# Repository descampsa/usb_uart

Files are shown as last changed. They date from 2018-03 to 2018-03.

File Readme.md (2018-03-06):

Isolated uart-usb converter.

Features:
- Silab CP2102N converter
- MAX12931 isolators
- Up to 3Mbaud UART, with hardware flow control (RTS/CTS)
- Supports 5V, 3.3V and 1.8V VCC
- Maximum withstand isolation voltage (VISO) : 3KV RMS
- Maximum working isolation voltage (VIOWM) : 445V RMS
- ABS plastic enclosure, with micro usb connector, and 0.1'' 6 pins header for uart

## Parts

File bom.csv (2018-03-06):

UBS_UART
N° Mouser | N° de fab. | Fabricant | N° client | Description | RoHS | Cycle de vie | Qté. | Prix (EUR) | Ext. : (EUR)
798-ZX62D-B-5PA830 | ZX62D-B-5PA8(30) | Hirose Electric |  | 5P RECEPTACLE | RoHS : conforme | Nouveau produit | 1 | 0,574 € | 0,57 €
538-22-28-8061 | 22-28-8061 | Molex |  | 2.54MM BREAKAWAY RA 6 CKT Tin | RoHS : conforme |  | 1 | 0,353 € | 0,35 €
710-885012206071 | 885012206071 | Wurth Electronics |  | WCAP-CSGP 100000pF 0603 10% 25V MLCC | RoHS : conforme |  | 6 | 0,04 € | 0,24 €
603-RC0603FR-071KL | RC0603FR-071KL | Yageo |  | 1K OHM 1% | RoHS : conforme |  | 4 | 0,082 € | 0,33 €
603-RC0603JR-074K7L | RC0603JR-074K7L | Yageo |  | 4.7K OHM 5% | RoHS : conforme |  | 2 | 0,082 € | 0,16 €
634-CP2102NA01GQFN20 | CP2102N-A01-GQFN20 | Silicon Laboratories |  | USB to UART bridge QFN20 | RoHS : conforme | Nouveau produit | 1 | 1,36 € | 1,36 €
700-MAX12931BASA+ | MAX12931BASA+ | Maxim Integrated |  | 2-Channel, 3.75kVRMS Digital Isolators | RoHS : conforme | Nouveau produit | 2 | 1,36 € | 2,72 €
789-P3A-20100562U | P3A-20100562U | New Age Enclosures |  | USB w/Open .062" PCB ABS Black 2x1x.5" | RoHS : conforme |  | 1 | 2,79 € | 2,79 €
749-VLP-250-R | VLP-250-R | BIVAR |  | Light Pipe Vert SMD Round Face | RoHS : conforme |  | 3 | 0,426 € | 1,28 €
530-0ZCJ0010FF2E | 0ZCJ0010FF2E | Bel |  | Fuse | RoHS : conforme |  | 1 | 0,09 € | 0,09 €
604-AP1608SRCPRV | AP1608SRCPRV | Kingbright |  | RED WATER CLEAR | RoHS : conforme |  | 3 | 0,107 € | 0,32 €
78-GMF05LC-HSF-GS08 | GMF05LC-HSF-GS08 | Vishay |  | ESD PRO LLP75-E4 | RoHS : conforme |  | 2 | 0,549 € | 1,10 €

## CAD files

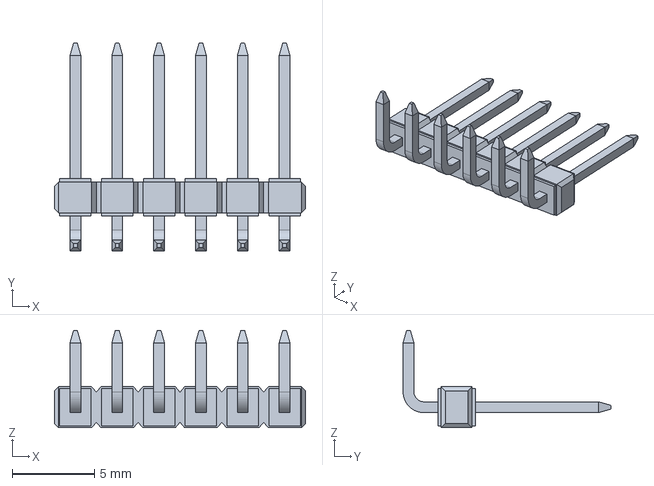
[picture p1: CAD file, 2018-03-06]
molex/022288061.step
15.2 x 12.6 x 5.92 mm

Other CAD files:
molex/022288061.stp

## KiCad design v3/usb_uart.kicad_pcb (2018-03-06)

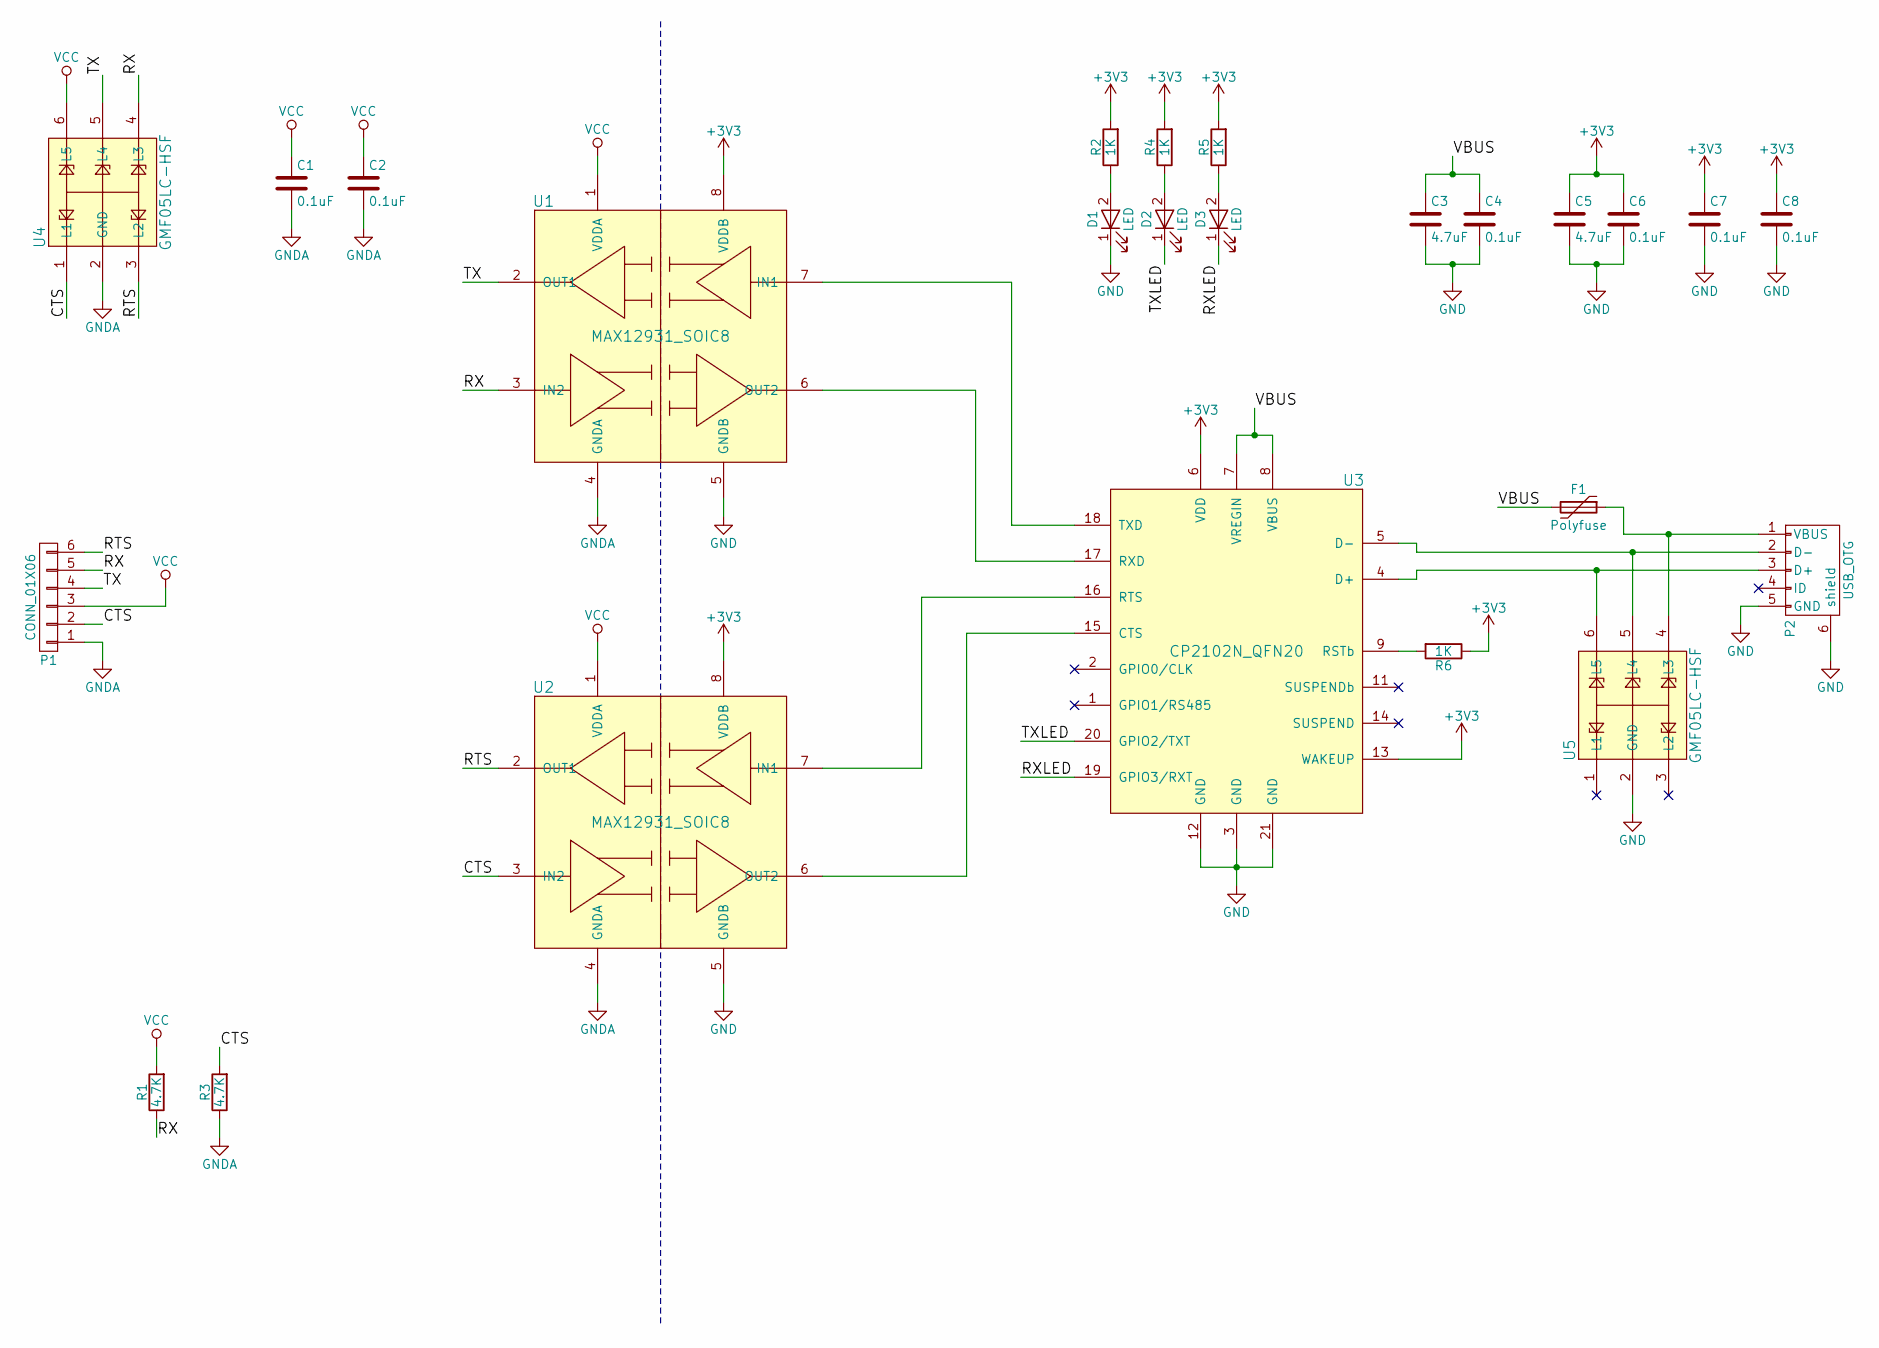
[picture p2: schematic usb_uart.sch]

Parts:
C1, C2, C4, C6, C7, C8: 0.1uF; C_0603
C3, C5: 4.7uF; C_0603
D1, D2, D3: LED; LED_0603
F1: Polyfuse; fuse_1206
P1: CONN_01X06; Pin_Header_Angled_1x06_Pitch2.54mm
P2: USB_OTG; ZX62D-B-5PA8
R1, R3: 4.7K; R_0603
R2, R4, R5, R6: 1K; R_0603
U1, U2: MAX12931_SOIC8; SOIC-8_3.9x4.9mm_Pitch1.27mm
U3: CP2102N_QFN20; QFN-20-1EP_3x3mm_Pitch0.5mm
U4, U5: GMF05LC-HSF; LLP75-6L

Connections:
+3V3: C5.1, C6.1, C7.1, C8.1, R2.2, R4.2, R5.2, R6.1, U1.8 (VDDB), U2.8 (VDDB), U3.6 (VDD), U3.13 (WAKEUP)
/CTS: P1.2, R3.2, U2.3 (IN2), U4.1 (L1)
/RTS: P1.6, U2.2 (OUT1), U4.3 (L2)
/RX: P1.5, R1.1, U1.3 (IN2), U4.4 (L3)
/RXLED: D3.1 (K), U3.19 (GPIO3/RXT)
/TX: P1.4, U1.2 (OUT1), U4.5 (L4)
/TXLED: D2.1 (K), U3.20 (GPIO2/TXT)
/VBUS: C3.1, C4.1, F1.2, U3.7 (VREGIN), U3.8 (VBUS)
GND: C3.2, C4.2, C5.2, C6.2, C7.2, C8.2, D1.1 (K), P2.5 (GND), P2.6 (shield), U1.5 (GNDB), U2.5 (GNDB), U3.3 (GND), U3.12 (GND), U3.21 (GND), U5.2 (GND)
GNDA: C1.2, C2.2, P1.1, R3.1, U1.4 (GNDA), U2.4 (GNDA), U4.2 (GND)
unnamed: D1.2 (A), R2.1
unnamed: D2.2 (A), R4.1
unnamed: D3.2 (A), R5.1
unnamed: F1.1, P2.1 (VBUS), U5.4 (L3)
unnamed: P2.2 (D-), U3.5 (D-), U5.5 (L4)
unnamed: P2.3 (D+), U3.4 (D+), U5.6 (L5)
unnamed: R6.2, U3.9 (RSTb)
unnamed: U1.6 (OUT2), U3.17 (RXD)
unnamed: U1.7 (IN1), U3.18 (TXD)
unnamed: U2.6 (OUT2), U3.15 (CTS)
unnamed: U2.7 (IN1), U3.16 (RTS)
VCC: C1.1, C2.1, P1.3, R1.2, U1.1 (VDDA), U2.1 (VDDA), U4.6 (L5)

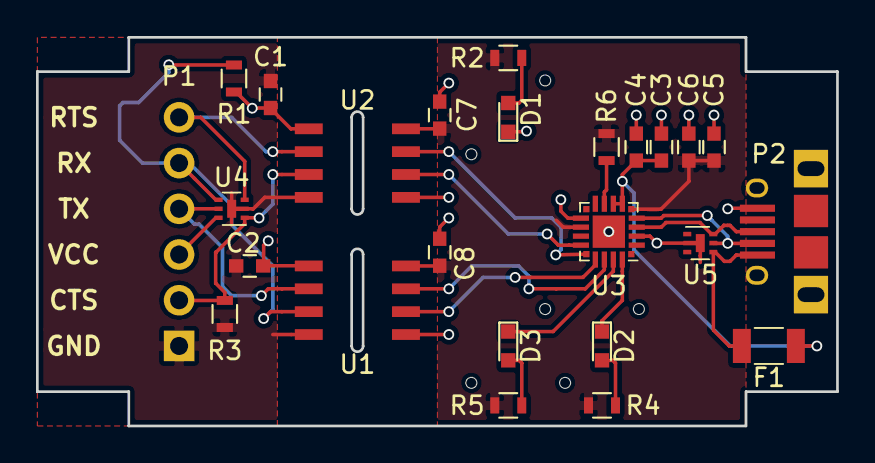
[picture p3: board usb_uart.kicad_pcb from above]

Board: 2 copper layers, 44.5 x 21.6 mm, 25 parts (0 on the bottom side), 22 nets.
